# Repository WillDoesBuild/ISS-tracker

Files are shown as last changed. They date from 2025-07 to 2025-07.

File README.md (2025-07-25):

# ISS-tracker
A physical ISS tracker that moves a model of the International Space Station around a globe using magnets. Uses an ESP32 to update the ISS location every 15 seconds from the Open Notify API. Here's a video about it!  (https://youtu.be/nbEe-BCNutg)

This GitHub repo only serves to hold files. Please see the Instructable about it here! (https://www.instructables.com/DIY-International-Space-Station-Tracker/)

<a href="https://creativecommons.org">ISS tracker</a> © 2025 by <a href="https://creativecommons.org">Will Dana</a> is licensed under <a href="https://creativecommons.org/licenses/by-nc-sa/4.0/">CC BY-NC-SA 4.0</a>

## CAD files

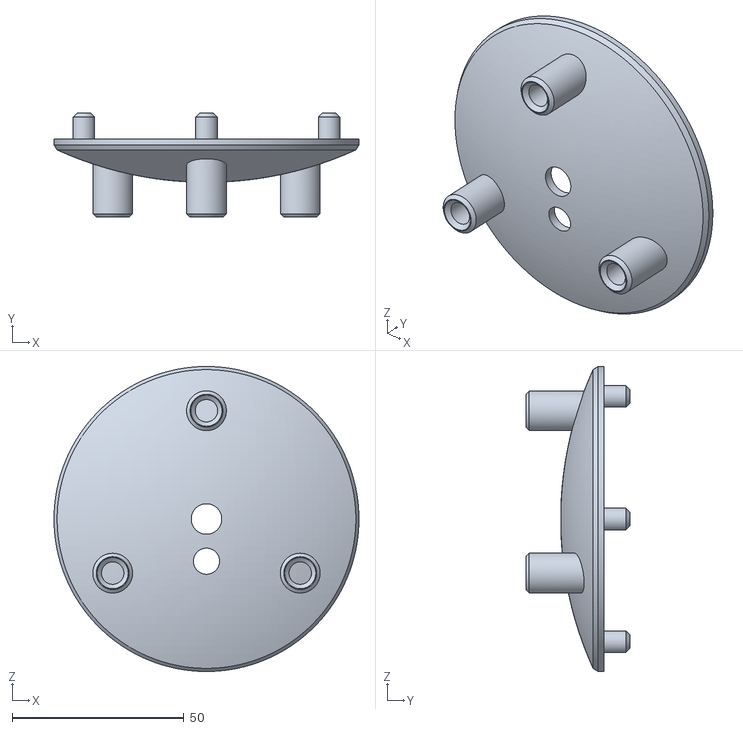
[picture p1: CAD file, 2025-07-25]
3D models/bottomCap.stl
88.9 x 30.5 x 88.9

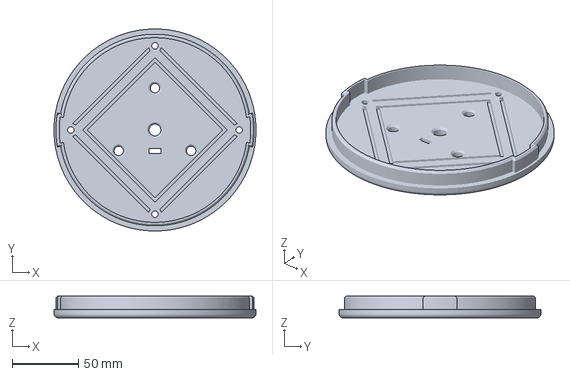
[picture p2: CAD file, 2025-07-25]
Prusa Project Files/baseLid.3mf
152.4 x 152.4 x 16.5 mm

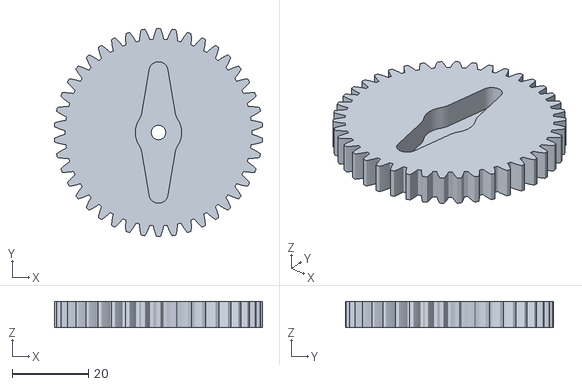
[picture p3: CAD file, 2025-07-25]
3D models/Spur Gear22.stl
54.5 x 54.6 x 6.86

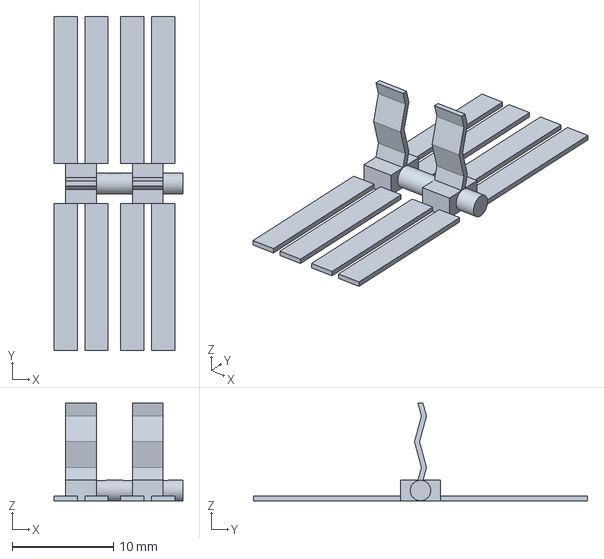
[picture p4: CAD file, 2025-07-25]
Prusa Project Files/issSide.3mf
12.8 x 33.1 x 9.65 mm

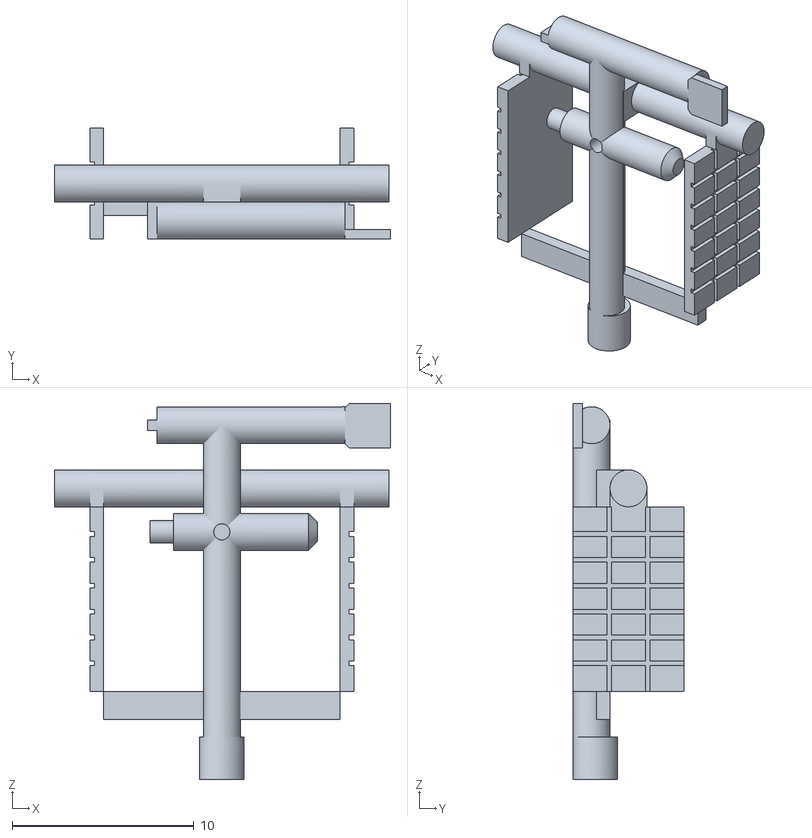
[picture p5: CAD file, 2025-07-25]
3D models/ISScenter.stl
18.5 x 6.10 x 20.7

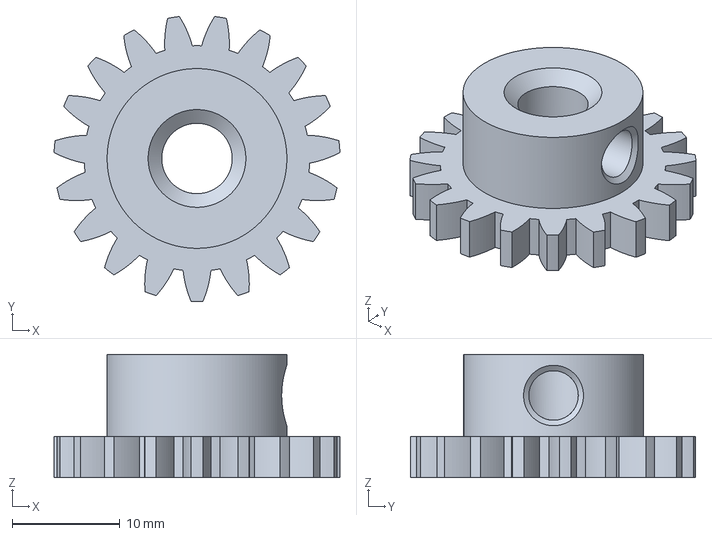
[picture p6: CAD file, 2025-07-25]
Prusa Project Files/Spur Gear12.3mf
26.6 x 26.5 x 11.4 mm

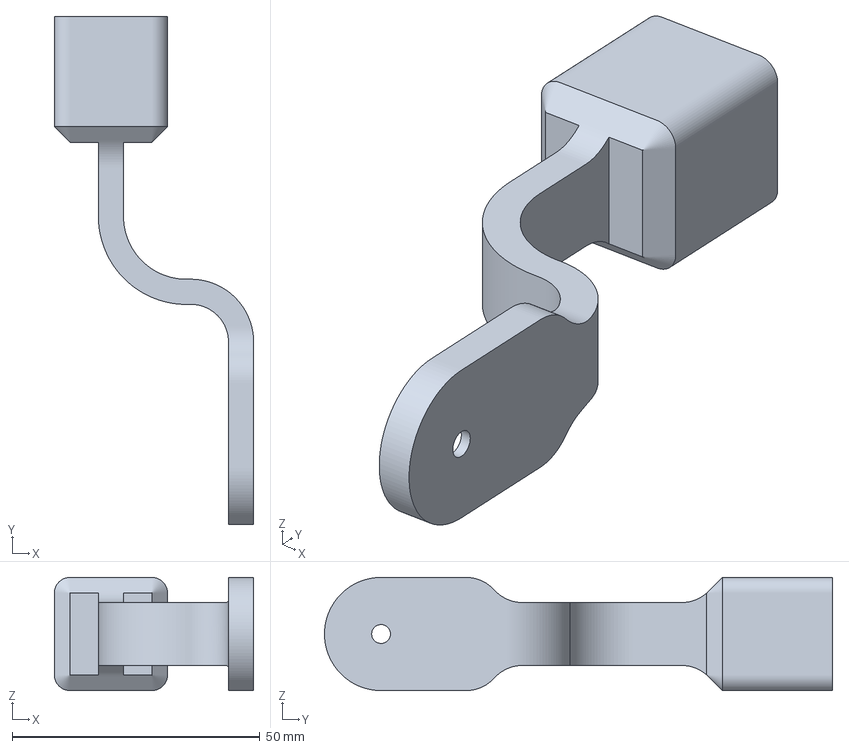
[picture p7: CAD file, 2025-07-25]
Prusa Project Files/latitudeArm.3mf
40.3 x 102.6 x 22.9 mm

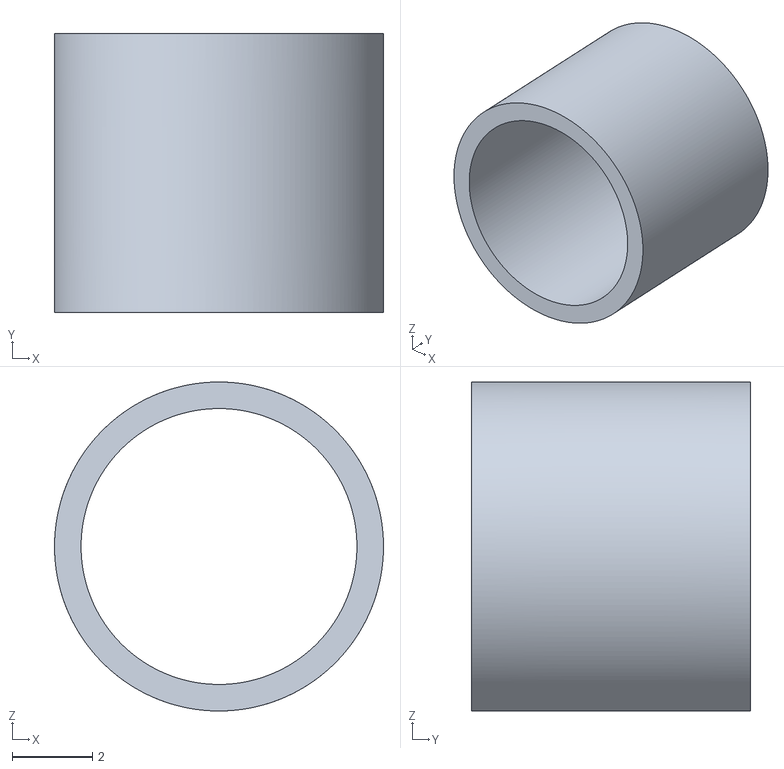
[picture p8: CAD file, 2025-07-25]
3D models/bearingAdapter.stl
8.18 x 6.93 x 8.18

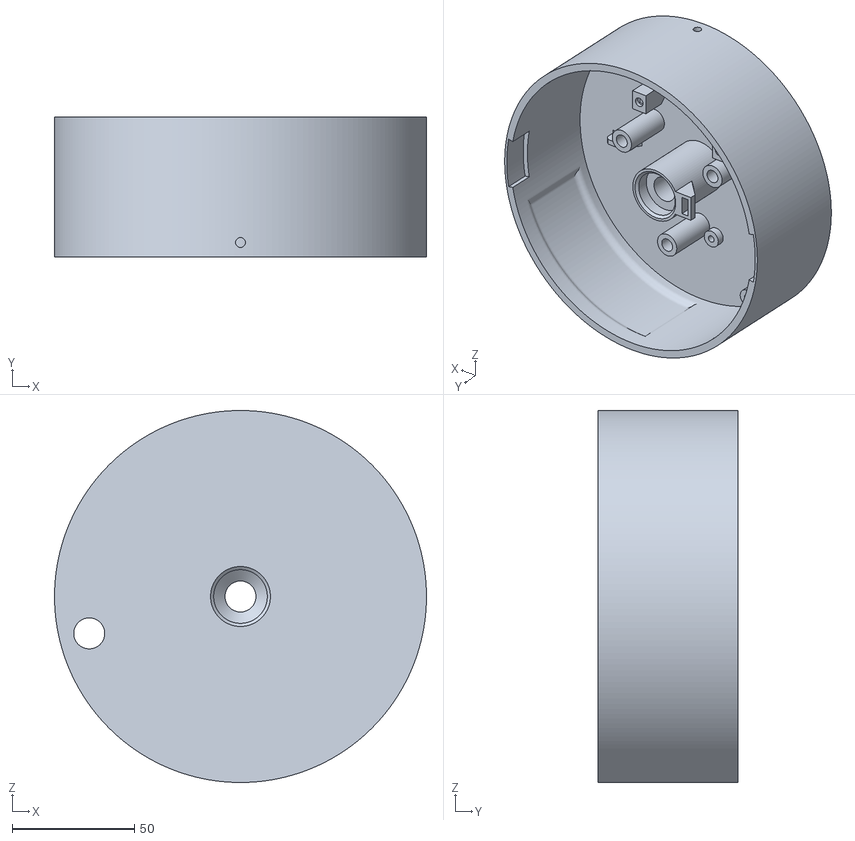
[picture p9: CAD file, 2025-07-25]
3D models/base.stl
152.4 x 57.2 x 152.4

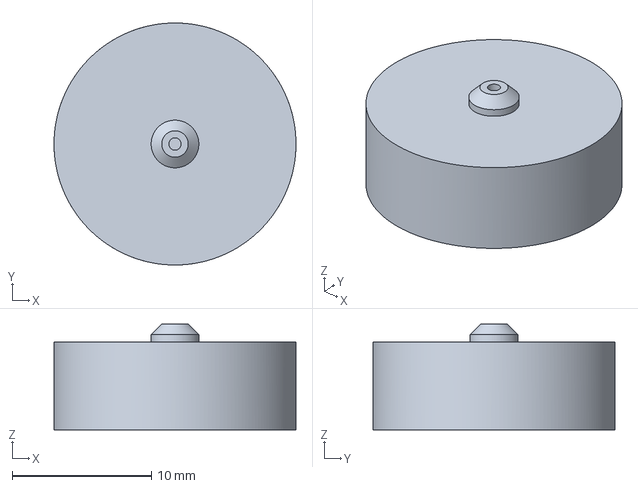
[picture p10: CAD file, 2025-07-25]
Prusa Project Files/ISSBase.3mf
17.4 x 17.4 x 7.61 mm

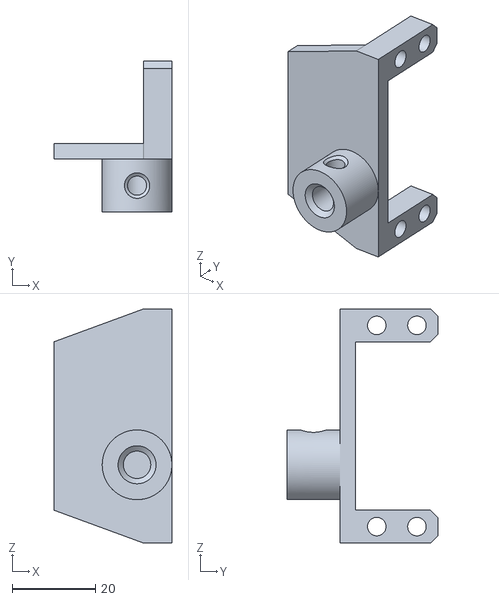
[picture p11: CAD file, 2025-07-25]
3D models/latitudeServoHolder.stl
28.3 x 36.3 x 56.2

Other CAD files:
3D models/baseLid.stl
Prusa Project Files/bearingAdapter.3mf
Prusa Project Files/ISScenter.3mf
3D models/issSide.stl
3D models/Spur Gear12.stl
Prusa Project Files/Spur Gear22.3mf
Prusa Project Files/latitudeServoHolder.3mf
3D models/ISSBase.stl
3D models/InsideMagnet.stl
3D models/latitudeArm.stl
Prusa Project Files/InsideMagnet.3mf
Prusa Project Files/base.3mf
Prusa Project Files/bottomCap.3mf

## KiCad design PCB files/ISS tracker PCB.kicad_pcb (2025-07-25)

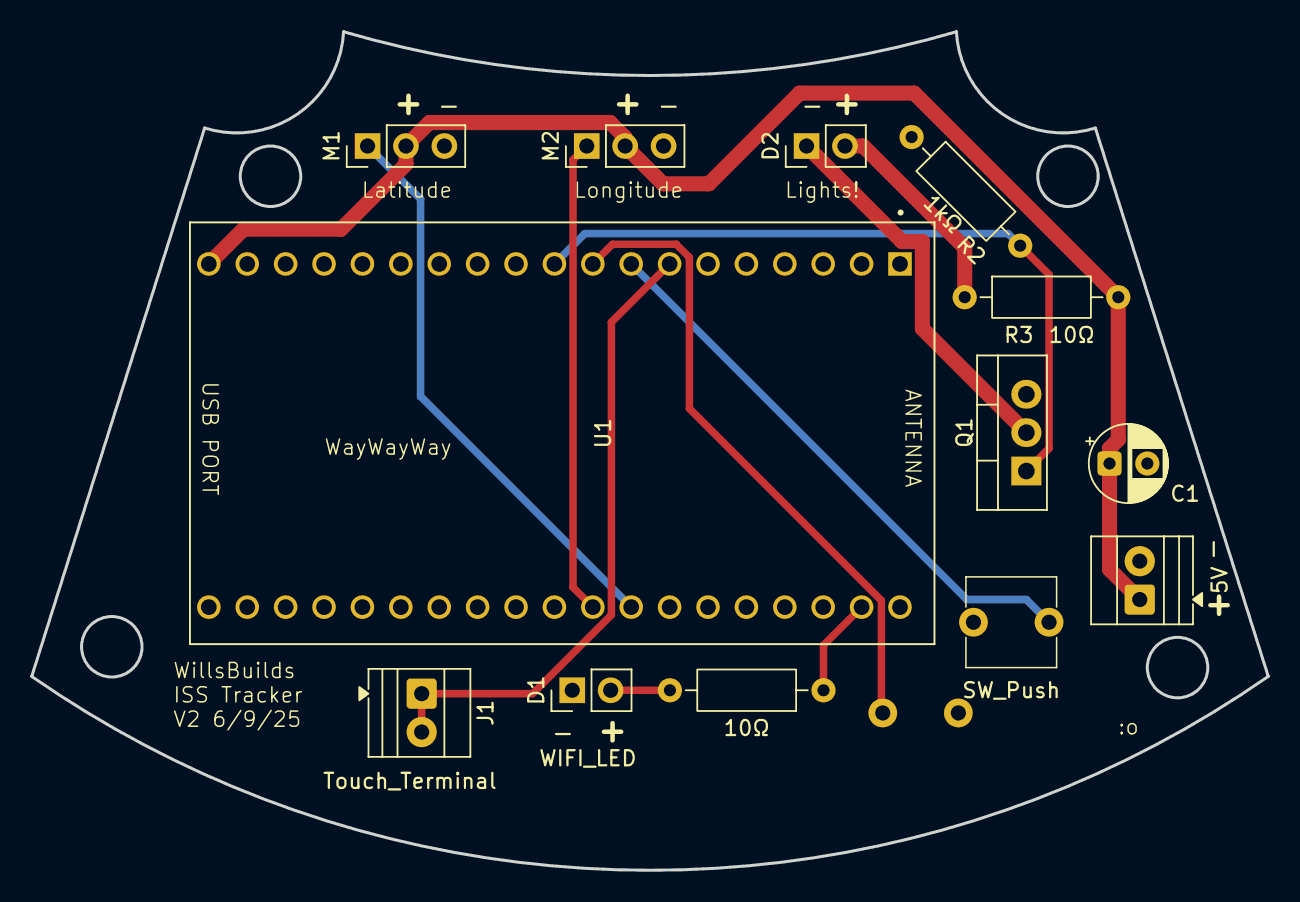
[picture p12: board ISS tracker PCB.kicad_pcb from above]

Board: 2 copper layers, 81.8 x 55.5 mm, 14 parts (1 on the bottom side), 12 nets.

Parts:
BT1: 5V; TerminalBlock_Xinya_XY308-2.54-2P_1x02_P2.54mm_Horizontal
C1: C; CP_Radial_D5.0mm_P2.50mm
D1: WIFI_LED; PinHeader_1x02_P2.54mm_Vertical
D2: LAMP_PARALLEL_LEDS; PinHeader_1x02_P2.54mm_Vertical
J1: Touch_Terminal; TerminalBlock_Xinya_XY308-2.54-2P_1x02_P2.54mm_Horizontal
M1: Long_Servo; PinHeader_1x03_P2.54mm_Vertical
M2: Lat_Servo; PinHeader_1x03_P2.54mm_Vertical
Q1: IRF540N; TO-220-3_Vertical
R1, R3: 10Ω; R_Axial_DIN0207_L6.3mm_D2.5mm_P10.16mm_Horizontal
R2: 1kΩ; R_Axial_DIN0207_L6.3mm_D2.5mm_P10.16mm_Horizontal
SW1: Calibrate; QTEATAK pushbutton
SW2: SW_Push; QTEATAK pushbutton
U1: ESP32-DEVKITC-32D; FIXEDMODULE_ESP32-DEVKITC-32D

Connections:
unnamed: BT1.1 (+), C1.1, M1.2 (+), M2.2 (+), R3.2, U1.J2-19 (EXT_5V)
unnamed: BT1.2 (-), C1.2, D1.1 (K), M1.3 (-), M2.3 (-), Q1.3 (S), R2.1, SW1.1, SW2.1, U1.J2-14 (GND1), U1.J3-1 (GND3)
unnamed: D1.2 (A), R1.2
unnamed: D2.2 (A), R3.1
unnamed: D2.1 (K), Q1.2 (D)
unnamed: J1.1, J1.2, U1.J2-7 (IO32)
unnamed: M1.1 (PWM), U1.J3-8 (IO19)
unnamed: M2.1 (PWM), U1.J3-9 (IO18)
unnamed: Q1.1 (G), R2.2, U1.J2-10 (IO26)
unnamed: R1.1, U1.J3-2 (IO23)
unnamed: SW1.2, U1.J2-9 (IO25)
unnamed: SW2.2, U1.J2-8 (IO33)

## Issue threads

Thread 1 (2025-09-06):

distance to ISS accuracy

Neon22, 2025-09-06:
I looked up ways to do this and I think the formula you mention has an error.

Arguably the best way to work it out is the Haversine calculation.
Given two pairs of latlong in degrees this works well within about 2% error.

Here's an accurate method written in python but easily translatable to Arduino:
```python
from math import radians, cos, sin, asin, sqrt
earth_rad = 6371.0088  # km  6367 sometimes

def haversine(latlong1, latlong2):
    """
    Calculate the great circle distance between two points
    on the earth (lat/long specified in decimal degrees)
    """
    lat1,lon1 = latlong1
    lat2,lon2 = latlong2
    # convert decimal degrees to radians
    lon1, lat1, lon2, lat2 = map(radians, [lon1, lat1, lon2, lat2])
    # haversine formula
    a = sin((lat2 - lat1) / 2) **2 + cos(lat1) * cos(lat2) * sin((lon2 - lon1) / 2) **2
    c = 2 * asin(sqrt(a))
    # 6367 km (or somesay 6371) is the radius of the Earth
    km = earth_rad * c
    return km
```
BTW - 1km = 0.621371 miles

You can test this with real world datapoints
e.g.
```python
lyon = (45.7597, 4.8422) # (lat, lon)
paris = (48.8567, 2.3508)

km = haversine(lyon, paris)
print(km)  # 392.217 calculated vs 392.66 actual
```

It might be worth noting that when the radius is below a certain amount then the ISS will be visible overhead.
The smaller the radius the more directly overhead the ISS will be.
However - if sun is up then probably not possible to see, also if the sun has set there may be no reflected light to see it by.
But if it is only just sunset or just before dawn, then light may hit it and it will be visible (if overhead)

I have not worked those factors out - but it could be a nice additional feature to have another LED that indicates when the ISS is visible/observable overhead and you could go outside and see it pass over.
Cheers...

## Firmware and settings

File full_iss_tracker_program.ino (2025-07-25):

//Thanks for making the ISS tracker! Open-sourcing this project was a lot of work, but I'm excited to see what people do with it! -Will, youtube.com/@willdoesbuild

#include <ESP32Servo.h>
#include <WiFi.h>
#include <ArduinoJson.h>
#include <HTTPClient.h>

//PUT YOUR WIFI CREDENTIALS HERE
const char* SSID = "Your SSID";
const char* PASSWORD =  "Your password";

Servo latitude;
Servo longitude;

#define longitudePin 18
#define latitudePin 19
#define button1Pin 25
#define button2Pin 33
#define WiFiLEDPin 23
#define lampLEDPin 26
#define lampTouchPin 32

float issLat;
float issLong;

static int longitudeMax = 2400;
static int longitudeMin = 620;

static int latitudeMax = 2500;
static int latitudeMin = 480;

short int currentLat = 0;
short int currentLong = 0;

bool lampState = 0;
bool touchRn;
long unsigned int lastUpdate = 0;

void initWiFi() {
  WiFi.mode(WIFI_STA);
  WiFi.begin(SSID, PASSWORD);
  Serial.print("Connecting to WiFi ..");
  while (WiFi.status() != WL_CONNECTED) {
    digitalWrite(WiFiLEDPin, HIGH);
    Serial.print('.');
    delay(1000);
  }
  Serial.println(WiFi.localIP());
  digitalWrite(WiFiLEDPin, LOW);
}

void setup() {
  Serial.begin(115200);

  longitude.attach(longitudePin);
  latitude.attach(latitudePin);

  pinMode(WiFiLEDPin, OUTPUT);
  pinMode(lampLEDPin, OUTPUT);
  pinMode(button1Pin, INPUT_PULLUP);
  pinMode(button2Pin, INPUT_PULLUP);

  initWiFi();

  goTo(0, -90);
  delay(1000);
  updateISSLocation();
  goToSlow(issLat, issLong);
}

void loop() {
  if (millis() - lastUpdate > 15000) {
    updateISSLocation();
    goToSlow(issLat, issLong);
    lastUpdate = millis();
  }
  //THIS HAS NOT BEEN TESTED YET, FUTURE WILL!!!!!!!!!
  if (WiFi.status() != WL_CONNECTED) {
    digitalWrite(WiFiLEDPin, HIGH);
  } else {
    digitalWrite(WiFiLEDPin, LOW);
  }

  if (touchRead(lampTouchPin) < 50) {
    if (touchRn == 0) {
      touchRn = 1;
      if (lampState == 0) {
        digitalWrite(lampLEDPin, HIGH);
        lampState = 1;
      } else {
        digitalWrite(lampLEDPin, LOW);
        lampState = 0;
      }
    }
  } else {
    touchRn = 0;
  }

  if (digitalRead(button1Pin) == LOW) {
    goToSlow(0, -90);
    delay(5000);
    updateISSLocation();
    goToSlow(issLat, issLong);
    lastUpdate = millis();
  }
}

//pull the ISS location from open notify and update the variables
void updateISSLocation() {
  digitalWrite(WiFiLEDPin, HIGH);

  if ((WiFi.status() == WL_CONNECTED)) {
    HTTPClient client;

    client.begin("http://api.open-notify.org/iss-now.json");
    int httpCode = client.GET();

    if (httpCode > 0) {
      String payload = client.getString();
      Serial.println("n\Statuscode: " + String(httpCode));
      Serial.println(payload);

      StaticJsonDocument<512> doc;
      DeserializationError error = deserializeJson(doc, payload);

      if (error) {
        Serial.print("JSON deserialization failed: ");
        Serial.println(error.c_str());
        return;
      }

      issLat = doc["iss_position"]["latitude"].as<float>();
      issLong = doc["iss_position"]["longitude"].as<float>();

      Serial.print("pulled latitude: ");
      Serial.println(issLat);
      Serial.print("pulled longitude: ");
      Serial.println(issLong);
    }
  } else {
    Serial.println("Connection Lost");
  }
  digitalWrite(WiFiLEDPin, LOW);
}

//slowly go to a given location
void goToSlow(int latTarget, int longTargetUnadjusted) {
  int longTarget;
  if (longTargetUnadjusted < 0) {
    longTarget = longTargetUnadjusted + 360;
  } else {
    longTarget = longTargetUnadjusted;
  }
  for (bool reachedPosition = false; reachedPosition != true;) {
    if (latTarget > currentLat) {
      latitudeGoTo(currentLat + 1);
      //Serial.println("added");
    } else if (latTarget < currentLat) {
      latitudeGoTo(currentLat - 1);
      //Serial.println("subtracted");
    }
    if (longTarget > currentLong) {
      longitudeGoTo(currentLong + 1);
    } else if (longTarget < currentLong) {
      longitudeGoTo(currentLong - 1);
    }
    delay(25);
    if (currentLat == latTarget && currentLong == longTarget) {
      reachedPosition = true;
      //Serial.println("reached position");
    }
  }
}

//go to a location quickly
void goTo(int latitude, int longitudeUnadjusted) {
  int longitude;
  if (longitudeUnadjusted < 0) {
    longitude = longitudeUnadjusted + 360;
  } else {
    longitude = longitudeUnadjusted;
  }
  latitudeGoTo(latitude);
  longitudeGoTo(longitude);
}

void longitudeGoTo(int angle) {
  longitude.writeMicroseconds(map(angle, 360, 0, longitudeMin, longitudeMax));
  currentLong = angle;
}

void latitudeGoTo(int angle) {
  latitude.writeMicroseconds(map(angle, -90, 90, latitudeMin, latitudeMax));
  currentLat = angle;
}
